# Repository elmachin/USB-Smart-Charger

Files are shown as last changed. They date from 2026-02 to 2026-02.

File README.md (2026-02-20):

# USB Smart Charger
**4-Port Intelligent Charging System Eliminating Phantom Power Drain**

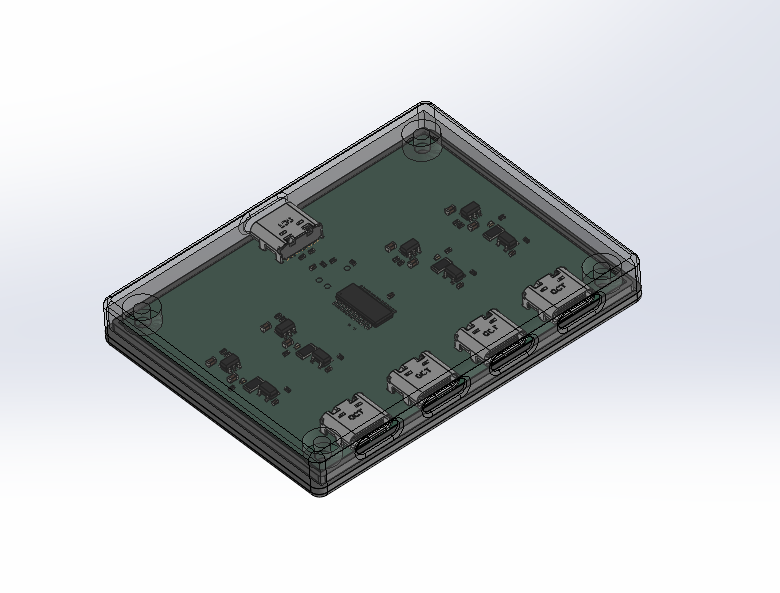
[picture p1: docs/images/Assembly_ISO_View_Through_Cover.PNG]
USB Smart Charger Assembly


---

## The Problem

Ever been annoyed in a dark room when a device that is fully charged continously wakes up, flashing LEDs and distrupting your sleep or Netflix show?

**The scenario:**
- You're watching TV or trying to sleep
- Your game controller is "fully charged" but still plugged in
- Every few minutes: bright LEDs flash as the device checks its charge state
- This happens because typical USB chargers provide continuous power, allowing devices to repeatedly check status and consume power even when they are fully charged

**Additional problems with always-on charging:**
- **Phantom power draw:** Even "idle" chargers consume power for status monitoring
- **Battery degradation:** Continuous trickle charging reduces battery lifespan
- **Energy waste:** Charging 4 devices overnight wastes significant power after they're full

---

## The Solution

A truly intelligent 4-port USB charger that **completely cuts power** after charging is complete, eliminating phantom draw, LED flashing, and unnecessary battery wear.

### How It Works

**1. Connection Detection (CC Line Monitoring)**
- Monitors USB-C CC (Configuration Channel) lines to detect device connection
- New device plugged in → power enabled, charging begins

**2. Intelligent Current Monitoring**
- Continuously measures charging current on each port independently
- When current drops below configurable threshold → device is fully charged

**3. Complete Power Cutoff**
- Disconnects power entirely to that port
- **Zero phantom power** - not even status checks
- Device stops all LED, and other activity

**4. Automatic Reset**
- Detects when device is unplugged and reconnected via CC line changes
- Charging cycle restarts automatically

### Key Innovation

Unlike "smart chargers" that reduce current or use timers, this design monitors actual current usage and completely disables current to the charged device.

---

## Features

- **4 independent ports** with individual monitoring and control
- **Zero phantom power** after charging complete
- **Per-port current sensing** with configurable shutoff threshold
- **Automatic reconnection detection** via CC line monitoring
- **Custom enclosure** designed for desktop use
- **Battery health preservation** by eliminating trickle charging

---

## Technical Specifications

**Charging:**
- 4 USB Type-A ports
- Independent current monitoring per port
- Configurable current threshold (10mA typical)
- Total output: 5V and up to 1.5A per each of the 4 ports

**Monitoring:**
- CC line state detection for plug/unplug events
- Automatic port cycling on reconnection

---

## Hardware Design

### PCB Design

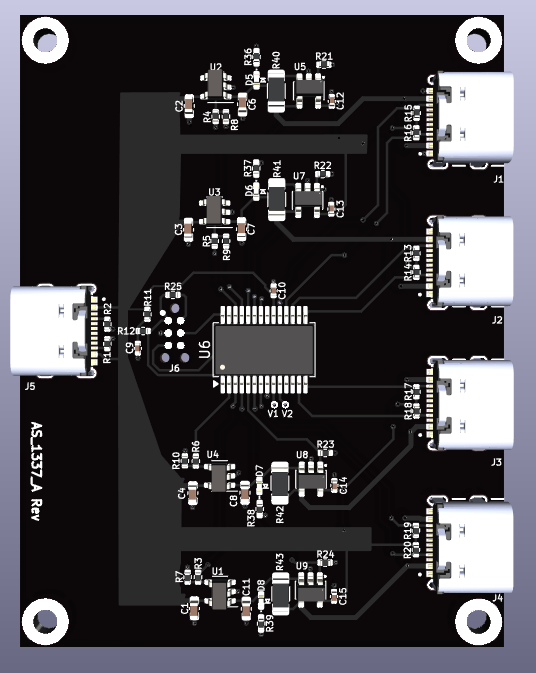
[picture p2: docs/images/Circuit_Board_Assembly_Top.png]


*PCB assembly - component placement*

### Enclosure Design

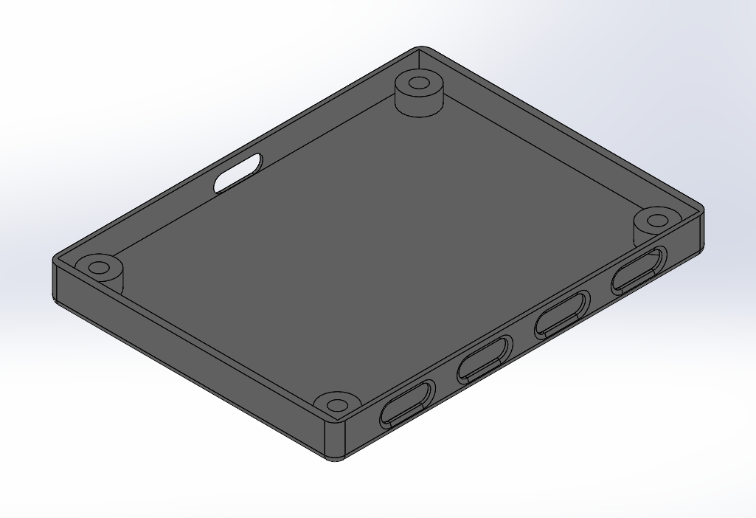
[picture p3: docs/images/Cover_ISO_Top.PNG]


*Custom designed enclosure - top view*

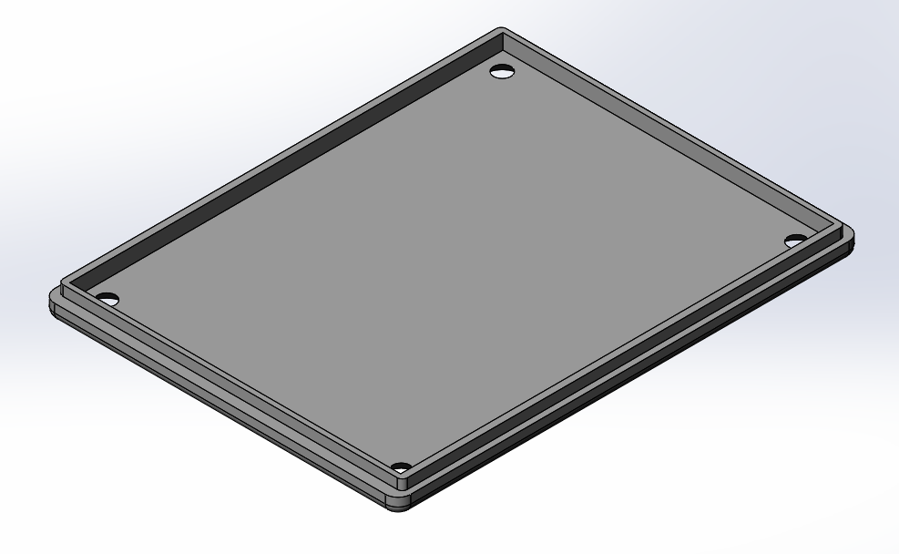
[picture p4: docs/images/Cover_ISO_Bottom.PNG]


*Enclosure bottom with mounting features*

---

## Design Files

### PCB Design
- **Schematic:** [View PDF](hardware/pcb/Schematic_Final.pdf)
- **BOM:** [View PDF](hardware/pcb/Assembly_Bill_of_Materials.pdf)
- **PCB Render:** [View Image](hardware/pcb/Circuit_Board_Assembly_Top.png)
- **Gerber Files:** Available in `/hardware/pcb/gerbers/` for manufacturing

### Mechanical Design
- **Top Enclosure:** [Download STEP](hardware/mechanical/Enclosure_Top.STEP)
- **Bottom Enclosure:** [Download STEP](hardware/mechanical/Enclosure_Bottom.STEP)

### Firmware
*Microcontroller firmware handles current monitoring, CC line detection, and port control logic*

---

## Use Cases

**Home Entertainment Setup**
- Charge multiple game controllers overnight without LED disturbance
- Eliminate phantom power from chargers left plugged in

**Workspace/Office**
- Charge phones, tablets, headphones during the day
- Automatic shutoff prevents overcharging and conserves energy

**Travel/Hotel**
- Compact design for charging multiple devices
- Battery health preservation for expensive electronics

**Energy Conscious Users**
- Measurable power savings vs. always-on chargers
- Zero standby consumption when devices are charged

---

## Design Approach

**Problem-Driven Engineering:**
This project started from a real annoyance (flashing controller LEDs) and evolved into a comprehensive solution addressing multiple charging inefficiencies.

**Key Technical Decisions:**
- **CC line monitoring** instead of just current sensing enables true plug/unplug detection
- **Complete power cutoff** eliminates all phantom draw
- **Per-port independence** prevents one slow-charging device from affecting others
- **Custom enclosure** provides clean desktop aesthetic

---

## Technical Implementation

**Current Sensing:**
- INA138

**Power Switching:**
- AP2191

**Microcontroller:**
- PIC16F19155
- Handles all monitoring and control logic

---
## Applications & Impact

**Personal Use:**
- Solved the original LED flashing annoyance
- Reduced measurable power consumption in home office
- Extended battery life of frequently charged devices

**Potential Commercial Applications:**
- Hotel rooms (eliminate phantom power, reduce complaints)
- Offices (energy savings across many desks)
- Retail displays (charge demo devices without battery degradation)

---

## Contact

Personal engineering project demonstrating embedded systems design, power electronics, and product development from concept to finished enclosure.

For technical questions or collaboration inquiries, please contact via GitHub.

---

*This project showcases full-stack hardware development: circuit design, PCB layout, firmware development, mechanical enclosure design, and solving real-world user experience problems.*

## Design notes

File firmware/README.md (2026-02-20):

# USB Smart Charger Firmware

Firmware for PIC16F19155 microcontroller managing 4-port intelligent USB charging with per-port current monitoring and automatic shutoff.

---

## Overview

This firmware implements a zero-phantom-power USB charging system that completely cuts power to devices after they finish charging, preventing LED flashing, trickle charging, and standby power consumption.

**Key Features:**
- Per-port USB CC line detection for plug/unplug events
- INA138-based current sensing on each port
- Configurable low-current shutdown threshold
- Persistence timer to prevent false shutoffs
- Boot-time visual LED feedback
- Automatic re-enable only on detach/reattach cycle

---

## Hardware Requirements

**Microcontroller:** PIC16F19155

**Pin Assignments:**

| Function | Pin | Port | Description |
|---|-----|---|---|
| **Port 1 Enable** | RB4 | Output | Power control for USB Port 1 |
| **Port 2 Enable** | RB5 | Output | Power control for USB Port 2 |
| **Port 3 Enable** | RA0 | Output | Power control for USB Port 3 |
| **Port 4 Enable** | RA1 | Output | Power control for USB Port 4 |
| **Port 1 Current** | RB3 (ANB3) | Analog Input | INA138 Vout for Port 1 |
| **Port 2 Current** | RB2 (ANB2) | Analog Input | INA138 Vout for Port 2 |
| **Port 3 Current** | RA3 (ANA3) | Analog Input | INA138 Vout for Port 3 |
| **Port 4 Current** | RA2 (ANA2) | Analog Input | INA138 Vout for Port 4 |
| **Port 1 CC1** | RC7 | Digital Input | USB Port 1 CC line 1 |
| **Port 1 CC2** | RB1 | Digital Input | USB Port 1 CC line 2 |
| **Port 2 CC1** | RC4 | Digital Input | USB Port 2 CC line 1 |
| **Port 2 CC2** | RC6 | Digital Input | USB Port 2 CC line 2 |
| **Port 3 CC1** | RC2 | Digital Input | USB Port 3 CC line 1 |
| **Port 3 CC2** | RC3 | Digital Input | USB Port 3 CC line 2 |
| **Port 4 CC1** | RA4 | Digital Input | USB Port 4 CC line 1 |
| **Port 4 CC2** | RA5 | Digital Input | USB Port 4 CC line 2 |

**ADC Configuration:**
- Reference: FVR 4.096V
- Resolution: 10-bit (0-1023)
- Conversion mode: Single conversion per channel

---

## Current Sensing

**INA138 High-Side Current Monitor:**
- Sense resistor (Rs): 0.5Ω
- Load resistor (Rl): 24kΩ
- Output voltage: Vout = (Iload × Rs) × (Rl / 1000)

**Current Calculation:**
```c
Iload (mA) = Vout (mV) / (Rs × Rl/1000)
Iload (mA) = Vout (mV) / (0.5 × 24) = Vout (mV) / 12
```

**Calibration Factor:** 1.2× applied to compensate for component tolerances

**Example:**
- 10mA load current
- 0.5Ω × 10mA = 5mV across sense resistor
- INA138 gain = 24
- Vout = 5mV × 24 = 120mV
- ADC reading: ~30 counts (120mV / 4096mV × 1024)

---

## Configuration Parameters

Located at top of `main.c`:
```c
// INA138 hardware values
#define RS_OHMS         0.5f        // Sense resistor value
#define RL_KOHMS        24.0f       // Load resistor value
#define CALIBRATION_FACTOR  1.4f    // Empirically determined

// Operational thresholds
#define LOW_CURRENT_MA      10.0f   // Shutdown threshold
#define PERSIST_MS          3000    // 3 second persistence timer

// ADC reference
#define VREF_mV         4096.0f     // FVR voltage
#define ADC_RESOLUTION  1024        // 10-bit ADC
```

**Adjustable Parameters:**

| Parameter | Default | Purpose | Recommended Range |
|---|---|---|---|
| `LOW_CURRENT_MA` | 10.0 | Current below which port shuts off | 5-50mA |
| `PERSIST_MS` | 3000 | Time below threshold before shutdown | 1000-5000ms |
| `CALIBRATION_FACTOR` | 1.4 | Component tolerance compensation | Measure on hardware |
| `BLINK_DELAY_MS` | 500 | Boot LED flash duration | 200-1000ms |

---

## Operating Logic

### Boot Sequence

1. **System Initialization**
   - Configure all pins (GPIO, ADC, enables)
   - Set up ADC with FVR reference
   - 100ms stabilization delay

2. **Visual Feedback**
   - Flash all 4 port LEDs twice (on/off cycles)
   - Final flash leaves all ports ON
   - Total boot sequence: ~3 seconds

3. **Initial Port Configuration**
   - Check CC lines on all 4 ports
   - Enable ports with devices already attached
   - Disable ports with nothing connected
   - Initialize state tracking for each port

### Main Loop (100ms cycle time)

**For each port (1-4), execute in order:**

#### 1. CC Line Detection
```
Read CC1 and CC2 pins
Device attached if EITHER CC line is LOW (pulled down by device)

IF (was detached AND now attached):
    → Turn port ON
    → Mark as enabled
    → Reset low-current timer

ELSE IF (was attached AND now detached):
    → Turn port OFF immediately
    → Mark as disabled
    → Reset low-current timer
```

#### 2. Current Monitoring (only if port enabled)
```
Read ADC on current sense channel
Convert to milliamps using INA138 formula

IF (current < LOW_CURRENT_MA):
    Increment low_timer by 100ms
    
    IF (low_timer >= PERSIST_MS):
        → Turn port OFF
        → Mark as disabled
        → Reset timer
        
ELSE (current >= LOW_CURRENT_MA):
    → Reset low_timer to 0 (device still charging)
```

#### 3. State Update
```
Save current CC state for next cycle comparison
```

---

## State Machine

**Port States:**
```
┌─────────────┐
│   DETACHED  │ ← No device connected, power OFF
└──────┬──────┘
       │ CC attach detected
       ↓
┌─────────────┐
│   CHARGING  │ ← Device connected, power ON, current > threshold
└──────┬──────┘
       │ Current < threshold for PERSIST_MS
       ↓
┌─────────────┐
│  COMPLETE   │ ← Device full, power OFF (still physically connected)
└──────┬──────┘
       │ CC detach detected
       ↓
┌─────────────┐
│   DETACHED  │ ← Device removed, ready for next device
└─────────────┘
```

**Critical:** Port will NOT re-enable from COMPLETE state unless device is physically unplugged and replugged (CC detach→attach cycle).

---

## Timing Characteristics

| Event | Response Time | Notes |
|---|---|---|
| Device plug-in | 100-200ms | Next main loop cycle |
| Device unplug | 100-200ms | Immediate shutoff on CC change |
| Charge complete shutoff | 3.0-3.1s | After current drops below threshold |
| Boot sequence | ~3s | Visual feedback duration |
| Main loop cycle | 100ms | Per-port update rate |

---

## Typical Use Case: Phone Charging

**Timeline:**
```
T=0s:       User plugs in phone
T=0.1s:     CC lines detected, port enabled, LED on
T=0-90min:  Phone charging, current 500-1500mA
T=90min:    Phone reaches 100%, current drops to ~5mA
T=90:00:    Low current detected, timer starts
T=90:03:    Timer expires (3s), port shuts off
            → Phone stops LED flashing
            → Zero phantom power consumption
            
User unplugs phone, replugs 8 hours later:
T=8hr:      CC attach detected, port re-enabled
            → Charging resumes
```

---

## Power Consumption

**Microcontroller:**
- Active: ~2mA @ 8MHz
- Per-port enable circuitry: <1mA

**Total system standby:** <10mW when all ports off

**Per-port active:** <50mW (enable + sensing)

---

## Troubleshooting

### Port won't turn on when device plugged in

**Check:**
1. CC line connections (RC7, RB1, RC4, RC6, RC2, RC3, RA4, RA5)
2. CC pulldown resistors on USB connector (5.1kΩ to GND)
3. Enable pin connections (RB4, RB5, RA0, RA1)
4. Power to enable circuitry

### Port turns off too quickly / won't stay on

**Solutions:**
1. Increase `PERSIST_MS` (e.g., 5000 for 5 seconds)
2. Lower `LOW_CURRENT_MA` threshold (e.g., 5.0mA)
3. Check calibration factor against actual measurements

### Port turns off at wrong current level

**Calibration procedure:**
1. Connect known load (e.g., 10mA constant current)
2. Observe when port shuts off
3. Adjust `CALIBRATION_FACTOR`:
   - If shuts off at 14mA target 10mA: factor = 1.4
   - If shuts off at 7mA target 10mA: factor = 0.7
   - Formula: `new_factor = old_factor × (actual_mA / target_mA)`

### Port won't re-enable after charging complete

**This is correct behavior!**

Port will only re-enable when:
1. Device is physically unplugged (CC lines go HIGH)
2. Device is replugged (CC lines go LOW again)

This is the core feature preventing phantom power and LED flashing.

---

## Development Environment

**Required Software:**
- MPLAB X IDE (v6.0 or later)
- XC8 Compiler (v2.40 or later)
- MPLAB Code Configurator (MCC) for peripheral setup

**MCC Configuration:**
- System Clock: 8MHz internal oscillator
- ADC: 10-bit, FVR 4.096V reference
- GPIO: Configure all pins per pin table above
- No interrupts required (polled operation)

---

## Building and Programming

**Build:**
```
1. Open project in MPLAB X
2. Build → Clean and Build Main Project
3. Verify 0 errors, 0 warnings
```

**Program:**
```
1. Connect PICkit or ICD to ICSP header
2. Run → Program Device
3. Observe boot LED sequence
```

**Verification:**
```
1. Boot: All LEDs should flash twice
2. Plug device: Port LED turns on
3. Wait for charge: Port LED turns off after 3s below threshold
4. Unplug/replug: Port LED turns back on
```
---

## License

See main project LICENSE file.

---

## Author

Part of the USB Smart Charger hardware project.

For hardware documentation, schematics, and PCB files, see parent directory.

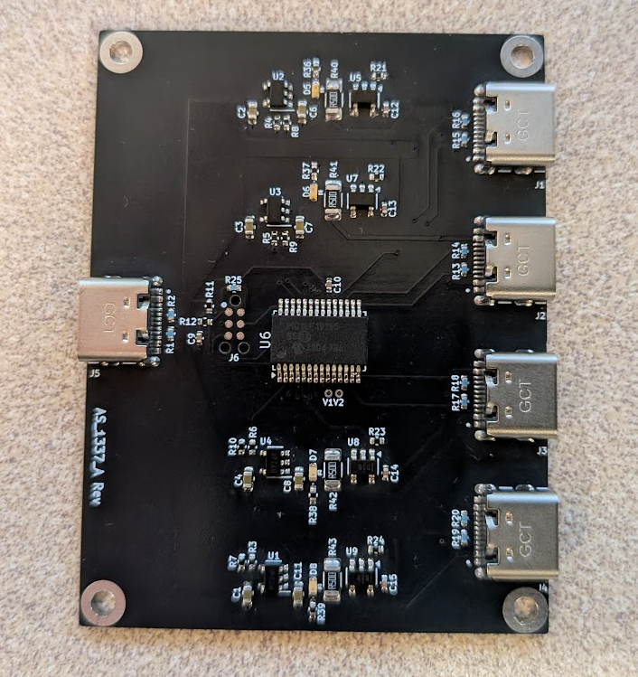
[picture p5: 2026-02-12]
hardware/pcb/Circuit_Board_Photo.png

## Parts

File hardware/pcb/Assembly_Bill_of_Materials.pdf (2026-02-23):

Source: | Four Port Charger)\Rev- | Eeschema 9.0.7
Date: | 2026-02-10T09:46:23-0700 | Component Count:
| | 66

66
Item | Qty | Reference | Value | Part No. | Description | Manuf #1 | Manuf #1 P/N | PCB Footprint
1 | 8 | C1, C2, C3, C4, C6, C7, C8, C11 | 4.7 uF | CC_0603X5R475K010V | Chip Capacitor, 0603, X5R, 4.7 uF, 10%, 10V | Taiyo Yuden | LMK107BJ475KA-T | 1DS_Capacitor:C_0603_1608Metric
2 | 6 | C9, C10, C12, C13, C14, C15 | 0.1 uF | CC_0402X7R104K016V | Chip Capacitor, 0402, X7R, 0.1 uF, 10%, 16V | Kemet | C0402C104K4RAC7411 | 1DS_Capacitor:C_0402_1005Metric
3 | 4 | D5, D6, D7, D8 | LED | DI_LED_0402_GRN | Diode, LED, SMT, Green, 0402, 13mcd@5mA | Panasonic | LNJ347W83RA | LED_SMD:LED_0402_1005Metric
4 | 4 | H1, H2, H3, H4 | MountingHole_Pad | HW_TBD | Hardware, TBD, Do Not Install | None | None | 1DS_Footprints:MountingHole_Num2_Plated
5 | 5 | J1, J2, J3, J4, J5 | USB_C | CN_USBC_RA_SMT | USBC receptacle, USB 2.0, Right Angle, SMT (16+8) | GCT | USB4105-GF-A | 1DS_Footprints:GCT_USB4105-GF-A
6 | 1 | J6 | TC2030-IDC-NL | HW_TBD | Hardware, TBD, Do Not Install | None | None | 1DS_Footprints:TAG_TC2030-IDC-NL
7 | 2 | R1, R2 | 5.11 k | CR_0402F5111 | Chip Resistor, 0402, 1%, 5.11K Ohm, 1/16W | Vishay/Dale | CRCW04025K11FKED | 1DS_Resistor:R_0402_1005Metric
8 | 4 | R3, R4, R5, R6 | 1 k | CR_0402F1001 | Chip Resistor, 0402, 1%, 1.00K Ohm, 1/16W | Samsung | RC1005F1001CS | 1DS_Resistor:R_0402_1005Metric
9 | 5 | R7, R8, R9, R10, R11 | 10 k | CR_0402F1002 | Chip Resistor, 0402, 1%, 10.0K Ohm, 1/16W | Vishay/Dale | RCG040210K0FKED | 1DS_Resistor:R_0402_1005Metric
10 | 1 | R12 | 100 | CR_0402F1000 | Chip Resistor, 0402, 1%, 100 Ohm, 1/16W | Yageo | RT0402FRE07100RL | 1DS_Resistor:R_0402_1005Metric
11 8 | | R13, R14, R15, R16, R17, R18, R19, R20 | 56 k | CR_0402F5602 | Chip Resistor, 0402, 1%, 56.0K Ohm, 1/16W | Yaego | RC0402FR-1356KL | 1DS_Resistor:R_0402_1005Metric
12 | 4 | R21, R22, R23, R24 | 24 k | CR_0402B2402 | Chip Resistor, 0402, .1% 24.0 k Ohm, 1/16W | Yageo | RT0402BRD0724KL | 1DS_Resistor:R_0402_1005Metric
13 | 1 | R25 | TBD | CR_TBD | Chip Resistor, TBD, Do Not Install | None | None | 1DS_Resistor:R_0402_1005Metric
14 | 4 | R36, R37, R38, R39 | 150 | CR_0402F1500 | Chip Resistor, 0402, 1%, 150 Ohm, 1/16W | Samsung | RC1005F151CS | 1DS_Resistor:R_0402_1005Metric
15 | 4 | R40, R41, R42, R43 | 0.5 | CR_1206FR500 | Chip Resistor, 1206, 1%, 0.500 Ohm, 1/4W | Yageo | PT1206FR-070R5L | 1DS_Resistor:R_1206_3216Metric
16 | 4 | U1, U2, U3, U4 | AP2191 | IC_AP2191WG | Power Distribution Switch, 2.1A Max, SOT25 | Diodes Incorporated | AP2191WG-7 | 1DS_Footprints:AP2191
17 | 4 | U5, U7, U8, U9 | INA138 | IC_INA138 | High Side Measurement Current Shunt Monitor, SOT23-5 | Texas Instruments | INA138NA | 1DS_Footprints:SOT-23-5
18 | 1 | U6 | PIC16F19155 | IC_PIC16F19155_SS | Pic Microcontroller, 28-SSOP | Microchip | PIC16F19155-I/SS | Package_SO:SSOP-28_5.3x10.2mm_P0.65mm
19 | 2 | V1, V2 | Vpad | CN_VPAD | PCB Artwork Only, No Physical Part, CN_VPAD | PCB Artwork Only | No Physical Part | 1DS_Footprints:Vpad
20 | 4 | | | IUA-256-1 | PEMS | PEM Engineering | IUA-256-1
21 | 4 | | | 96640A021 | 2-56 3/16" Phillips Black-Oxide Flat Head Screw | McMaster-CARR | 96640A021

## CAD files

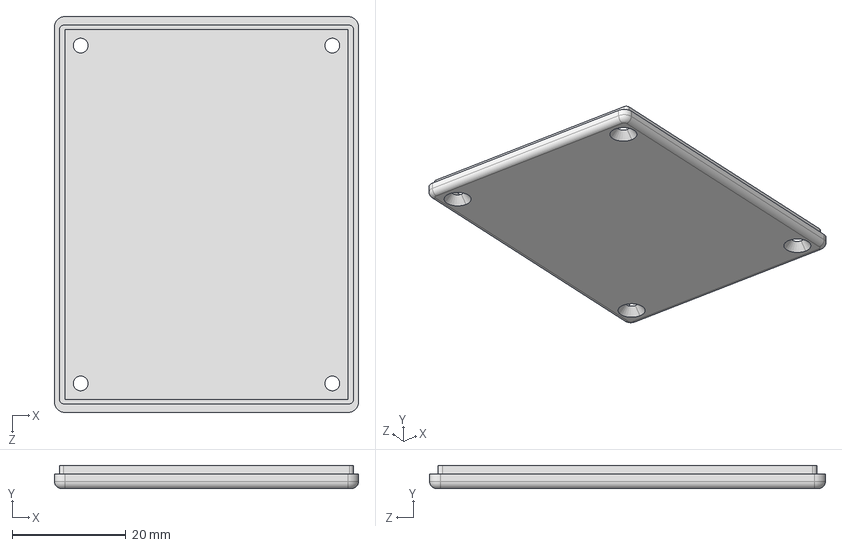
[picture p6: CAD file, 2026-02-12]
hardware/mechanical/Enclosure_Bottom.STEP
53.6 x 4.06 x 69.7 mm

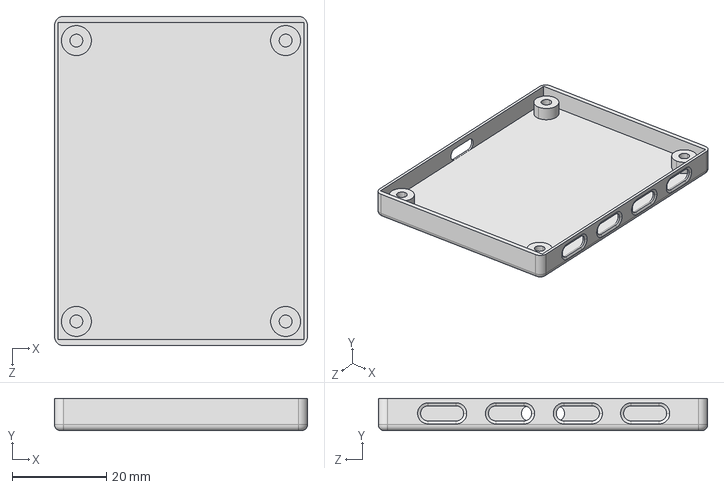
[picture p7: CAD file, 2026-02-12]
hardware/mechanical/Enclosure_Top.STEP
53.6 x 6.86 x 69.7 mm

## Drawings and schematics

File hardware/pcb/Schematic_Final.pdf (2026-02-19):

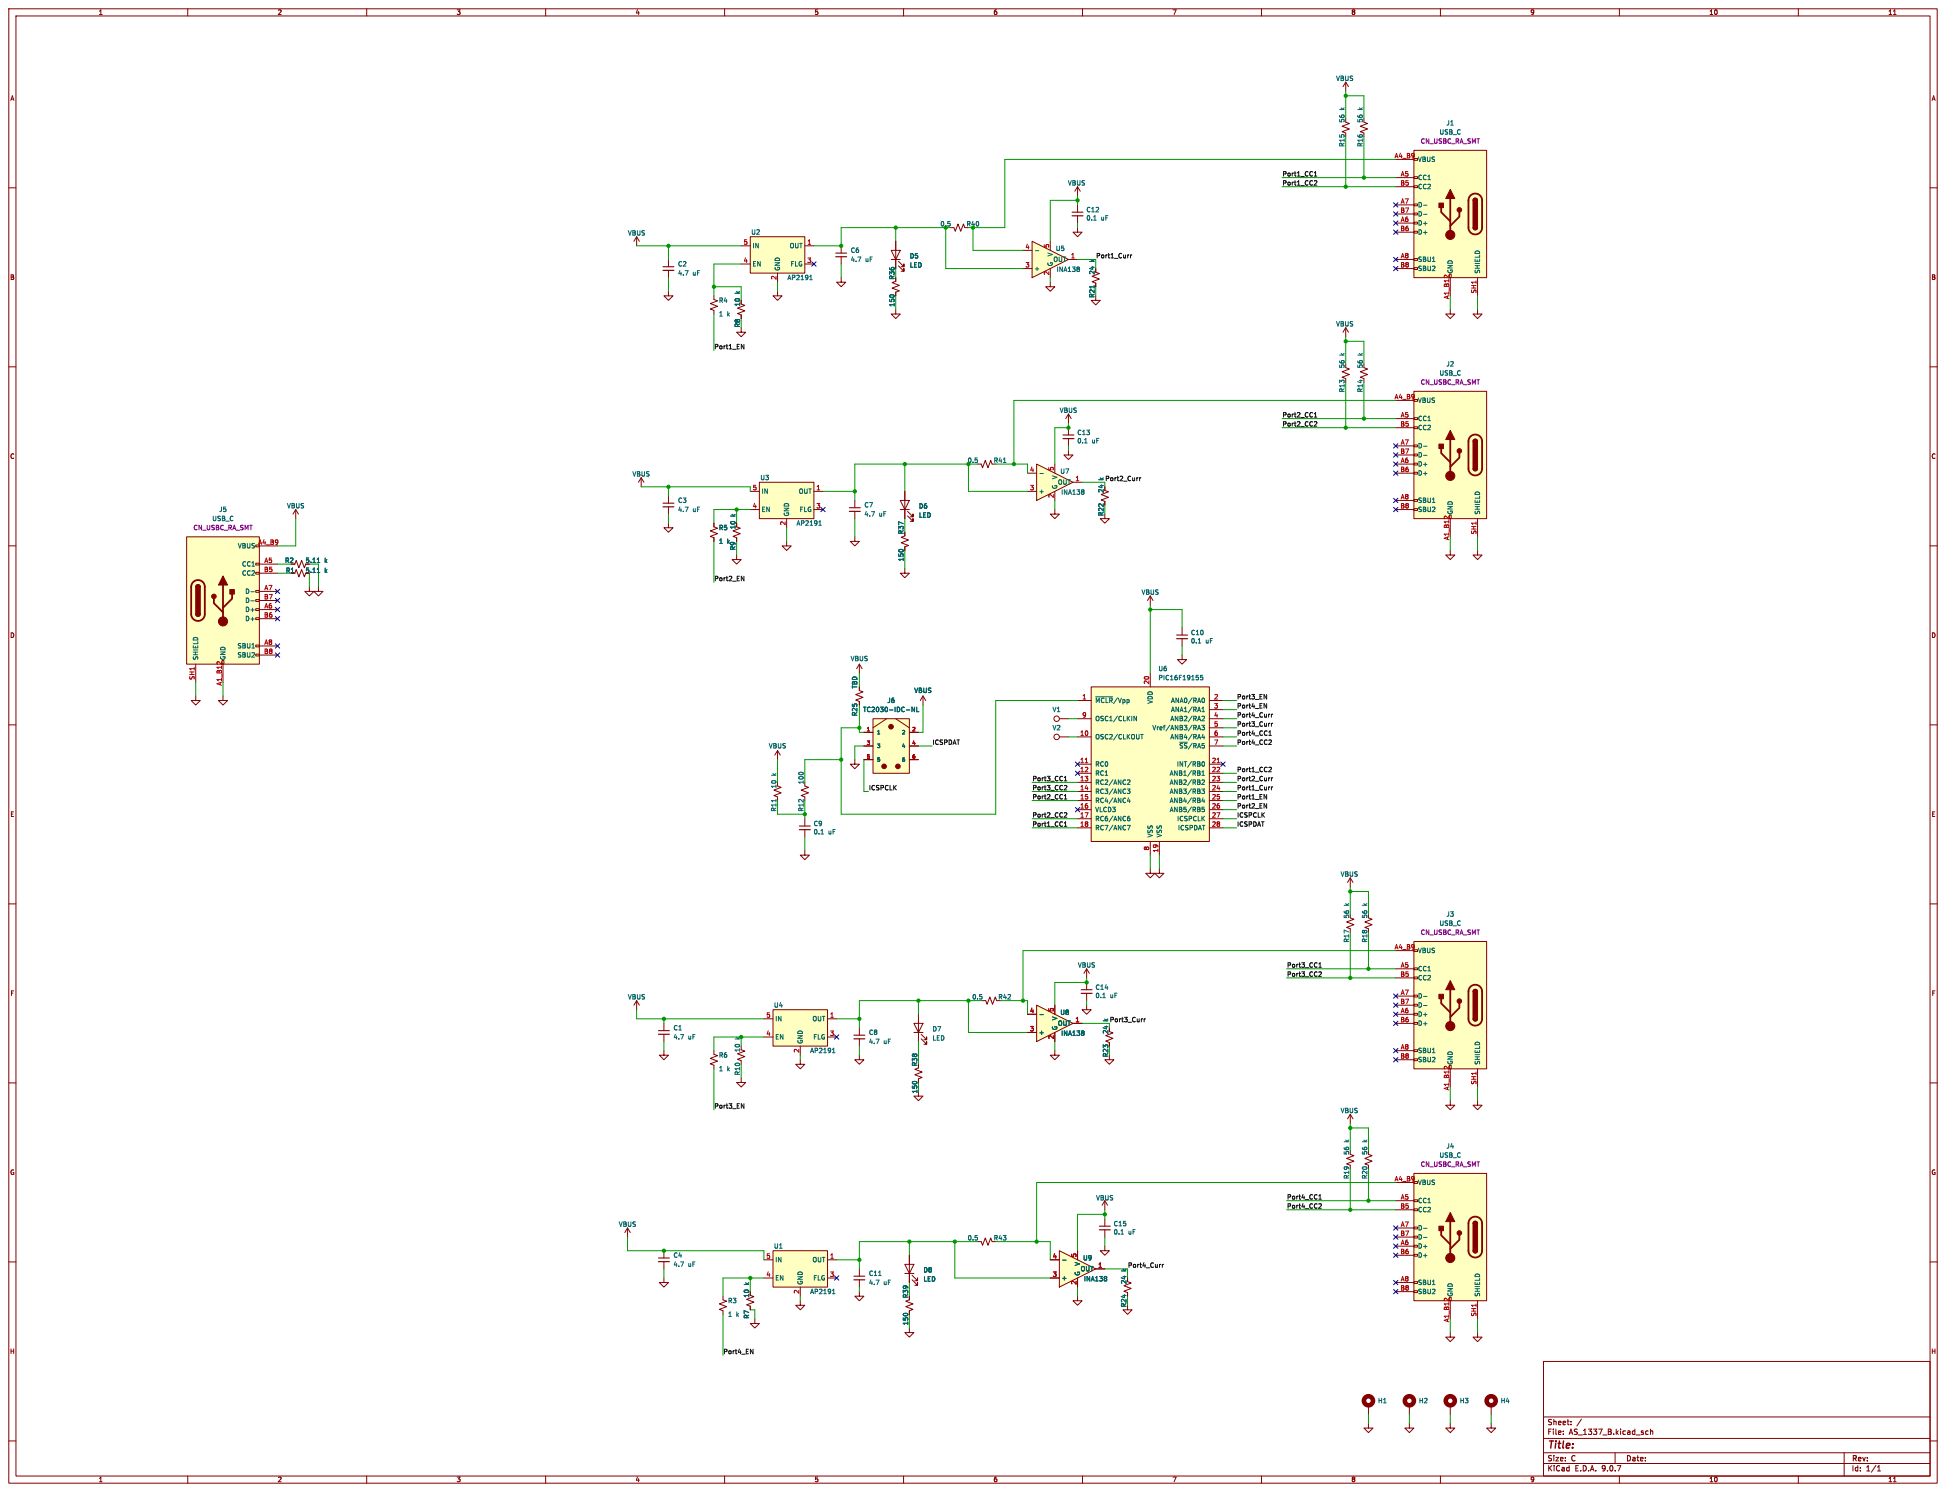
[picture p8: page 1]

Id: 1/1 Title: File: AS_1337_B.kicad_sch Sheet: /

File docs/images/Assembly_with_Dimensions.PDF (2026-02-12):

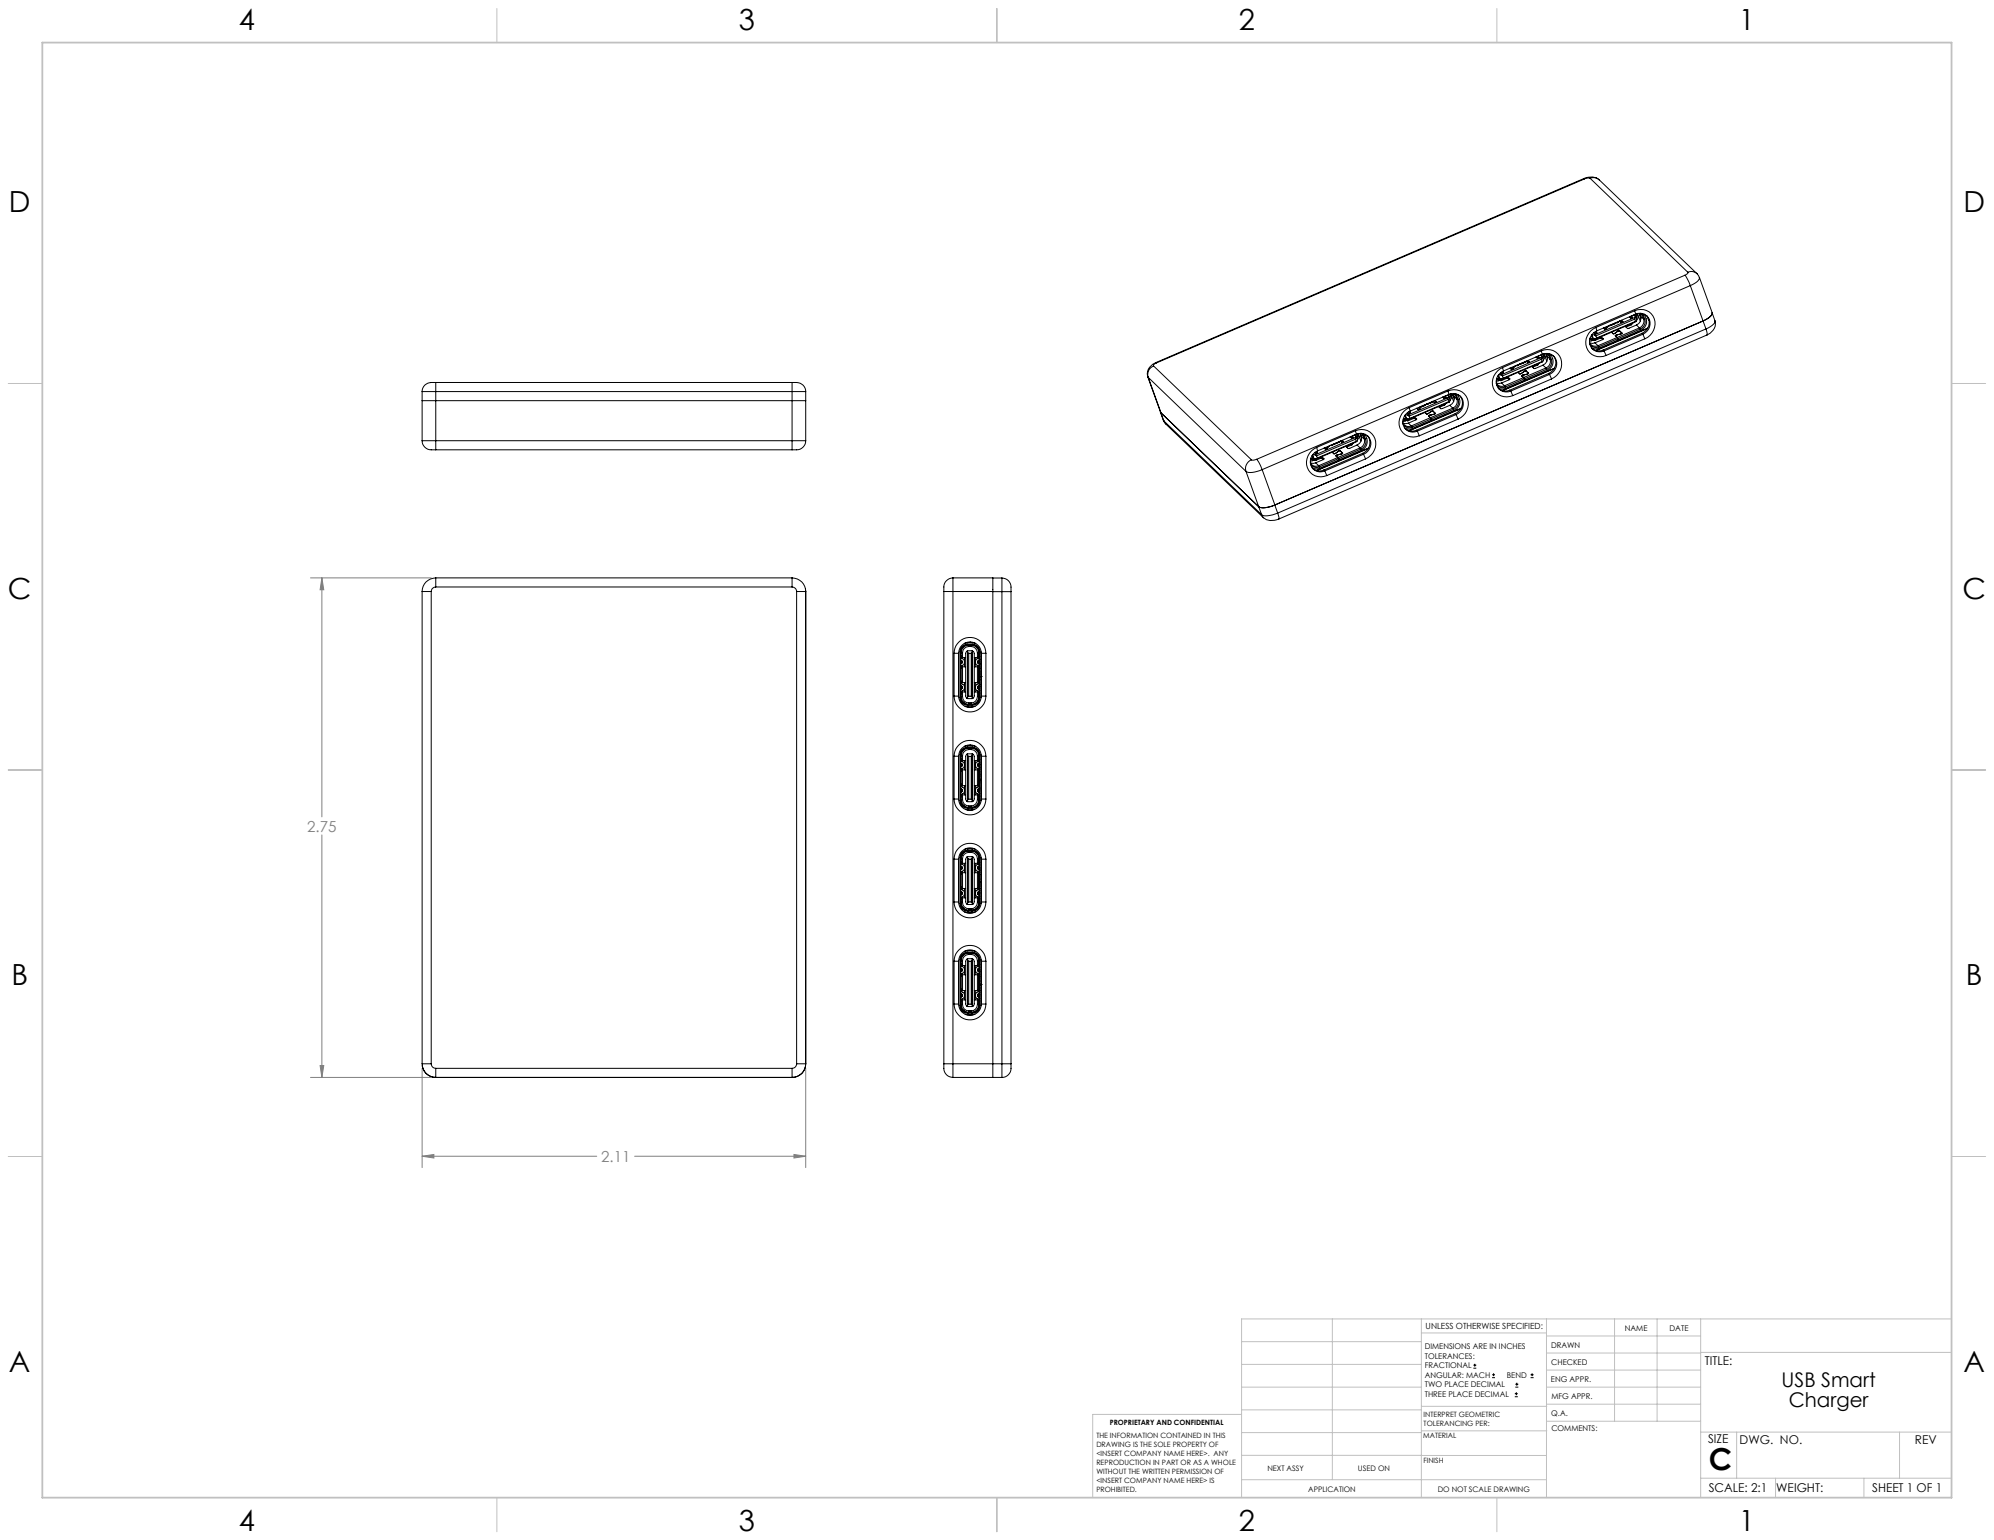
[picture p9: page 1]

UNLESS OTHERWISE SPECIFIED: | | NAME | DATE
DIMENSIONS ARE IN INCHES TOLERANCES: FRACTIONAL ANGULAR: MACH BEND TWO PLACE DECIMAL THREE PLACE DECIMAL | DRAWN

CHECKED | | | TITLE: USB Smart Charger

ENG APPR.
MFG APPR.

INTERPRET GEOMETRIC TOLERANCING PER: | Q.A.
MATERIAL | | SIZE C | DWG. NO. | REV

PROPRIETARY AND CONFIDENTIAL
THE INFORMATION CONTAINED IN THIS
DRAWING IS THE SOLE PROPERTY OF
<INSERT COMPANY NAME HERE>. ANY
REPRODUCTION IN PART OR AS A WHOLE
WITHOUT THE WRITTEN PERMISSION OF
<INSERT COMPANY NAME HERE> IS
PROHIBITED.

NEXT ASSY | USED ON | FINISH

APPLICATION | DO NOT SCALE DRAWING | | SCALE: 2:1 | WEIGHT: | SHEET 1 OF 1

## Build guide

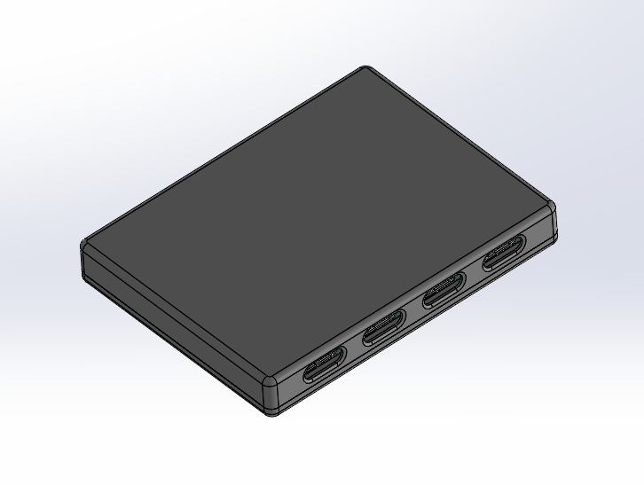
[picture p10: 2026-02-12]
docs/images/Assembly_ISO_View_Top.PNG

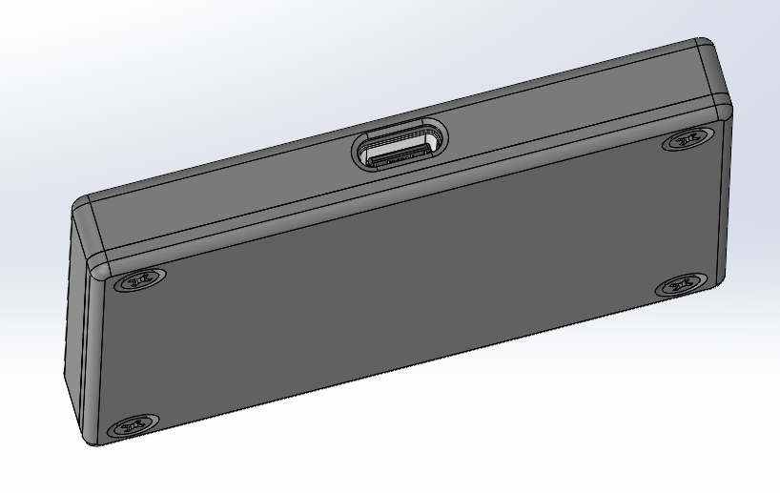
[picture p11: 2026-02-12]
docs/images/Assembly_ISO_View_Bottom.PNG

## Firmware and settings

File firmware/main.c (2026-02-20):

#include "mcc_generated_files/system/system.h"
#include "mcc_generated_files/adc/adc.h"

#include <stdint.h>
#include <stdbool.h>

// INA138 parameters
#define RS_OHMS         0.5f
#define RL_OHMS        24000.0f

// Thresholds
#define LOW_CURRENT_MA      10.0f
#define RE_ENABLE_MA        20.0f
#define PERSIST_MS          3000
#define CALIBRATION_FACTOR  1.2f    // for resistor tolerance

// ADC channels
#define CH_PORT1_CURR   Port1_Curr   // ADC_CHANNEL_ANB3
#define CH_PORT2_CURR   Port2_Curr   // ADC_CHANNEL_ANB2
#define CH_PORT3_CURR   Port3_Curr   // ADC_CHANNEL_ANA3
#define CH_PORT4_CURR   Port4_Curr   // ADC_CHANNEL_ANA2


// Enable pin macros (high = ON / LED on, assuming active-high)
#define PORT1_EN_ON()   LATBbits.LATB4 = 1
#define PORT1_EN_OFF()  LATBbits.LATB4 = 0
#define PORT2_EN_ON()   LATBbits.LATB5 = 1
#define PORT2_EN_OFF()  LATBbits.LATB5 = 0
#define PORT3_EN_ON()   LATAbits.LATA0 = 1
#define PORT3_EN_OFF()  LATAbits.LATA0 = 0
#define PORT4_EN_ON()   LATAbits.LATA1 = 1
#define PORT4_EN_OFF()  LATAbits.LATA1 = 0

// CC detection (low = 0 = device attached)
#define PORT1_CC_ATTACHED()  ((PORTBbits.RB1 == 0) || (PORTCbits.RC7 == 0))   // RB1=Port1_CC2, RC7=Port1_CC1
#define PORT2_CC_ATTACHED()  ((PORTCbits.RC6 == 0) || (PORTCbits.RC4 == 0))   // RC6=Port2_CC2, RC4=Port2_CC1
#define PORT3_CC_ATTACHED()  ((PORTCbits.RC2 == 0) || (PORTCbits.RC3 == 0))   // RC2=Port3_CC1, RC3=Port3_CC2
#define PORT4_CC_ATTACHED()  ((PORTAbits.RA4 == 0) || (PORTAbits.RA5 == 0))   // RA4=Port4_CC1, RA5=Port4_CC2


// Simple delay (approximate, adjust if needed)
#define BLINK_DELAY_MS  500

//ADC defines
#define ADC_RESOLUTION 1024
#define VREF_mV 4096.0f // FVR = 4.096V

// Port state structure
typedef struct {
    bool prev_cc_attached;      // Previous CC state
    bool enabled;               // Port power enabled
    uint32_t low_timer_ms;      // Low current timer
} PortState_t;

PortState_t port_state[4] = {
    {false, false, 0},
    {false, false, 0},
    {false, false, 0},
    {false, false, 0}
};


// Read voltage (mV)
float read_vout_mV(adc_channel_t channel) {
    adc_result_t raw = ADC_ChannelSelectAndConvert(channel);
    return (raw * VREF_mV) / ADC_RESOLUTION;
}

// Calculate current (mA)
float current_from_vout(float vout_mV) {
    float raw_current = (vout_mV * 1000.0f) / (RS_OHMS * RL_OHMS);
    return raw_current * CALIBRATION_FACTOR;
}

float getCurrent_mA(adc_channel_t channel) {
    float vout = read_vout_mV(channel);
    return current_from_vout(vout);
}


void blink_all_three_times(void) {
    for (int i = 0; i < 2; i++) {
        // All ON
        PORT1_EN_ON();
        PORT2_EN_ON();
        PORT3_EN_ON();
        PORT4_EN_ON();
        __delay_ms(BLINK_DELAY_MS);

        // All OFF
        PORT1_EN_OFF();
        PORT2_EN_OFF();
        PORT3_EN_OFF();
        PORT4_EN_OFF();
        __delay_ms(BLINK_DELAY_MS);
    }
    //Then Turn On all
    PORT1_EN_ON();
    PORT2_EN_ON();
    PORT3_EN_ON();
    PORT4_EN_ON();
    __delay_ms(BLINK_DELAY_MS);
}

void set_ports_based_on_cc(void) {
    // Port 1
    if (!PORT1_CC_ATTACHED()) {
        PORT1_EN_OFF();
    }

    // Port 2
    if (!PORT2_CC_ATTACHED()) {
        PORT2_EN_OFF();
    }

    // Port 3
    if (!PORT3_CC_ATTACHED()) {
        PORT3_EN_OFF();
    }

    // Port 4
    if (!PORT4_CC_ATTACHED()) {
        PORT4_EN_OFF();
    }
}


// Initialize port states based on CC detection at boot
void initialize_ports(void) {
    // Port 1
    port_state[0].prev_cc_attached = PORT1_CC_ATTACHED();
    if (port_state[0].prev_cc_attached) {
        PORT1_EN_ON();
        port_state[0].enabled = true;
    } else {
        PORT1_EN_OFF();
        port_state[0].enabled = false;
    }

    // Port 2
    port_state[1].prev_cc_attached = PORT2_CC_ATTACHED();
    if (port_state[1].prev_cc_attached) {
        PORT2_EN_ON();
        port_state[1].enabled = true;
    } else {
        PORT2_EN_OFF();
        port_state[1].enabled = false;
    }

    // Port 3
    port_state[2].prev_cc_attached = PORT3_CC_ATTACHED();
    if (port_state[2].prev_cc_attached) {
        PORT3_EN_ON();
        port_state[2].enabled = true;
    } else {
        PORT3_EN_OFF();
        port_state[2].enabled = false;
    }

    // Port 4
    port_state[3].prev_cc_attached = PORT4_CC_ATTACHED();
    if (port_state[3].prev_cc_attached) {
        PORT4_EN_ON();
        port_state[3].enabled = true;
    } else {
        PORT4_EN_OFF();
        port_state[3].enabled = false;
    }
}


void main(void) {
    // Initialize everything from MCC (pins, clock, etc.)
    SYSTEM_Initialize();

     // Small delay for stability
    __delay_ms(100);

    // Step 1: Boot blink sequence (all ports flash 3 times)
    blink_all_three_times();

    // Step 2: After blinking, enable only ports with device attached (CC low)
    set_ports_based_on_cc();
    
    initialize_ports();
    
    // Persistence timers (ms) for each port
    //uint32_t low_timer[4] = {0};
    
    // Forever loop
     while (1) {
        // ========== PORT 1 ==========
        bool cc1_now = PORT1_CC_ATTACHED();
        
        // Detect attach event (was detached, now attached)
        if (!port_state[0].prev_cc_attached && cc1_now) {
            PORT1_EN_ON();
            port_state[0].enabled = true;
            port_state[0].low_timer_ms = 0;
        }
        // Detect detach event (was attached, now detached)
        else if (port_state[0].prev_cc_attached && !cc1_now) {
            PORT1_EN_OFF();
            port_state[0].enabled = false;
            port_state[0].low_timer_ms = 0;
        }
        port_state[0].prev_cc_attached = cc1_now;

        // Current monitoring (only if enabled)
        if (port_state[0].enabled) {
            float i1 = getCurrent_mA(CH_PORT1_CURR);
            if (i1 < LOW_CURRENT_MA) {
                port_state[0].low_timer_ms += 100;
                if (port_state[0].low_timer_ms >= PERSIST_MS) {
                    PORT1_EN_OFF();
                    port_state[0].enabled = false;
                    port_state[0].low_timer_ms = 0;
                }
            } else {
                port_state[0].low_timer_ms = 0;
            }
        }

        // ========== PORT 2 ==========
        bool cc2_now = PORT2_CC_ATTACHED();
        
        if (!port_state[1].prev_cc_attached && cc2_now) {
            PORT2_EN_ON();
            port_state[1].enabled = true;
            port_state[1].low_timer_ms = 0;
        }
        else if (port_state[1].prev_cc_attached && !cc2_now) {
            PORT2_EN_OFF();
            port_state[1].enabled = false;
            port_state[1].low_timer_ms = 0;
        }
        port_state[1].prev_cc_attached = cc2_now;

        if (port_state[1].enabled) {
            float i2 = getCurrent_mA(CH_PORT2_CURR);
            if (i2 < LOW_CURRENT_MA) {
                port_state[1].low_timer_ms += 100;
                if (port_state[1].low_timer_ms >= PERSIST_MS) {
                    PORT2_EN_OFF();
                    port_state[1].enabled = false;
                    port_state[1].low_timer_ms = 0;
                }
            } else {
                port_state[1].low_timer_ms = 0;
            }
        }

        // ========== PORT 3 ==========
        bool cc3_now = PORT3_CC_ATTACHED();
        
        if (!port_state[2].prev_cc_attached && cc3_now) {
            PORT3_EN_ON();
            port_state[2].enabled = true;
            port_state[2].low_timer_ms = 0;
        }
        else if (port_state[2].prev_cc_attached && !cc3_now) {
            PORT3_EN_OFF();
            port_state[2].enabled = false;
            port_state[2].low_timer_ms = 0;
        }
        port_state[2].prev_cc_attached = cc3_now;

        if (port_state[2].enabled) {
            float i3 = getCurrent_mA(CH_PORT3_CURR);
            if (i3 < LOW_CURRENT_MA) {
                port_state[2].low_timer_ms += 100;
                if (port_state[2].low_timer_ms >= PERSIST_MS) {
                    PORT3_EN_OFF();
                    port_state[2].enabled = false;
                    port_state[2].low_timer_ms = 0;
                }
            } else {
                port_state[2].low_timer_ms = 0;
            }
        }

        // ========== PORT 4 ==========
        bool cc4_now = PORT4_CC_ATTACHED();
        
        if (!port_state[3].prev_cc_attached && cc4_now) {
            PORT4_EN_ON();
            port_state[3].enabled = true;
            port_state[3].low_timer_ms = 0;
        }
        else if (port_state[3].prev_cc_attached && !cc4_now) {
            PORT4_EN_OFF();
            port_state[3].enabled = false;
            port_state[3].low_timer_ms = 0;
        }
        port_state[3].prev_cc_attached = cc4_now;

        if (port_state[3].enabled) {
            float i4 = getCurrent_mA(CH_PORT4_CURR);
            if (i4 < LOW_CURRENT_MA) {
                port_state[3].low_timer_ms += 100;
                if (port_state[3].low_timer_ms >= PERSIST_MS) {
                    PORT4_EN_OFF();
                    port_state[3].enabled = false;
                    port_state[3].low_timer_ms = 0;
                }
            } else {
                port_state[3].low_timer_ms = 0;
            }
        }

        __delay_ms(100);  // 100ms update interval
    }
}

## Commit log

2026-02-12 Revise README for improved clarity and detail
    Updated README to enhance clarity and detail about the USB Smart Charger features and functionality.
2026-02-19 updated resistor values
